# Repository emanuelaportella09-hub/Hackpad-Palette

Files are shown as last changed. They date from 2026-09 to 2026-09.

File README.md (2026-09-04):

# Hackpad-Palette
A Hackpad where you can switch colors on Paint for Windows 11.

I tried to make a keyboard for when I use Paint, to change colors like a real palette.

IT ONLY WORKS FOR PAINT ON WINDOWS 11.
IT WON'T WORK FOR OTHER SOFTWARE.

It was fun to make, and it taught me more about the production process of keyboards. It's really interesting, because out there is a whole community that loves this kind of hardware.

# FEATURES
- 128x32 OLED display
- 16 keys
- Can change colors on Paint on Windows 11

# PCB
I used EasyEDA for this project since I know how to use it a little, unlike KiCad.




# SCHEMATICS
SCH_Schematic1_1-P1_2026-09-04

# CAD
Plate only



Case and plate



Case, plate, and PCB all together. I couldn't put the 3D file of the PCB in Onshape because it was buggy for some reason, so I decided to put a rectangle inside with the same measurements as the board instead.



# BOM

16x MX Switches

1x XIAO RP2040

16x Differently Colored DSA Keycaps

4x M3x16 Bolt

4x M3 Heatset

1x 0.91" 128x32 OLED Display

16x Through-hole 1N4148 Diodes

1x Case.step in PRODUCTION FOLDER needs to be 3d printed

1x Plate.step in PRODUCTION FOLDER needs to be 3d printed

#**EXTRA NEDDED:**

Soldering Iron

My firmware

Arduino IDE installed on a computer

AutoHotKey installed on a computer

#**TESTING:**

Few Jump Wires

Breadboard

Usb-c to usb cable

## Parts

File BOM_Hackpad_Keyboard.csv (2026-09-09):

Item | Component / Part | Quantity | Category | Notes
1 | MX Switches | 16 | Hardware / Component | Key switches
2 | XIAO RP2040 | 1 | Microcontroller | Main MCU board
3 | DSA Keycaps (Differently Colored) | 16 | Hardware | Keycaps
4 | M3x16 Bolt | 4 | Fastener | Hardware mounting
5 | M3 Heatset Insert | 4 | Fastener | 3D print insert
6 | 0.91" 128x32 OLED Display | 1 | Display | I2C OLED screen
7 | 1N4148 Diodes (Through-hole) | 16 | Electronic Component | Switch matrix diodes
8 | Case.step | 1 | 3D Print | Located in PRODUCTION FOLDER (Needs 3D printing)
9 | Plate.step | 1 | 3D Print | Located in PRODUCTION FOLDER (Needs 3D printing)
10 | Soldering Iron | 1 | Extra Needed / Tool | Assembly tool
11 | Firmware | 1 | Software / Code | Custom keyboard firmware
12 | Arduino IDE | 1 | Software | Installed on computer
13 | AutoHotKey | 1 | Software | Installed on computer
14 | Jump Wires | 1 | Testing Equipment | Few wires for breadboarding
15 | Breadboard | 1 | Testing Equipment | For testing before soldering
16 | USB-C to USB Cable | 1 | Testing Equipment / Cable | Power and data connection

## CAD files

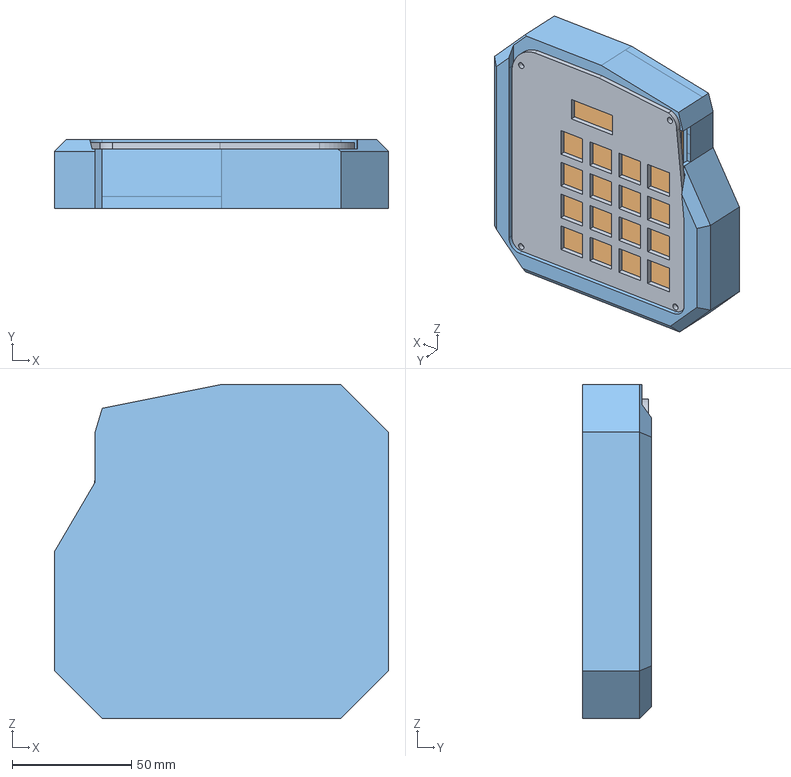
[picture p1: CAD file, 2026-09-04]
CAD/hackpad.step
140.0 x 29.0 x 140.0 mm
plate
pcb
case

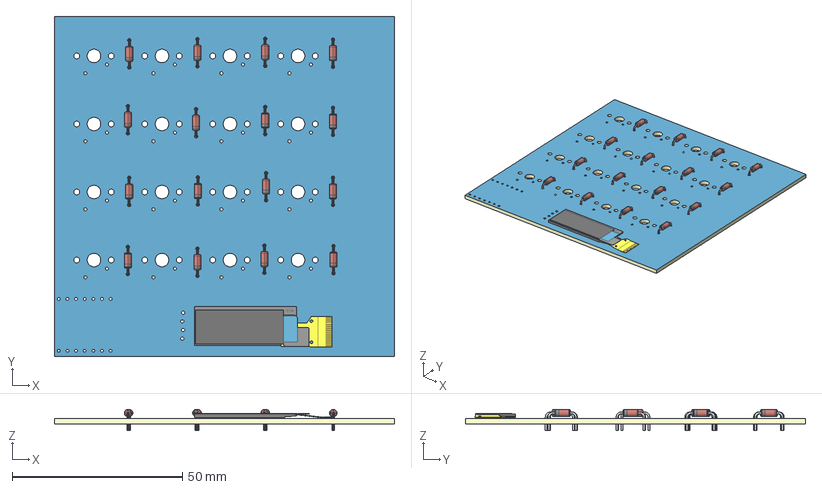
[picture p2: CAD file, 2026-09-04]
PCB/3D_PCB1_2026-09-04.step
100.0 x 100.0 x 6.21 mm
Board~ctDM
TopCopper~ctDM
BottomCopper~ctDM
TopSilkscreen~ctDM
BottomSilkscreen~ctDM
TopFpcStiffener~ctDM
BottomFpcStiffener~ctDM
DO-35_BD2.0-L4.0-P8.00-D0.5-FD~DO-35_BD2.0-L4.0-P8.00-D0.5-FD~vYH5 x 16
OLED-TH-C128-R64-D0.91-I2C-SSD1306-STAG5~OLED_L40.5-W11.5-H1.2-QG-2832TLBFG02~vior

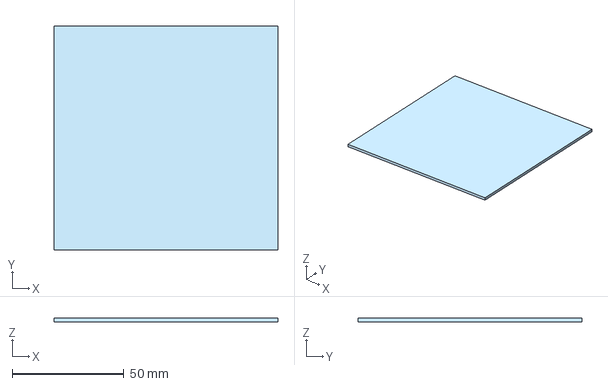
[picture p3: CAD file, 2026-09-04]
CAD/pcb.step
100.0 x 100.0 x 1.60 mm

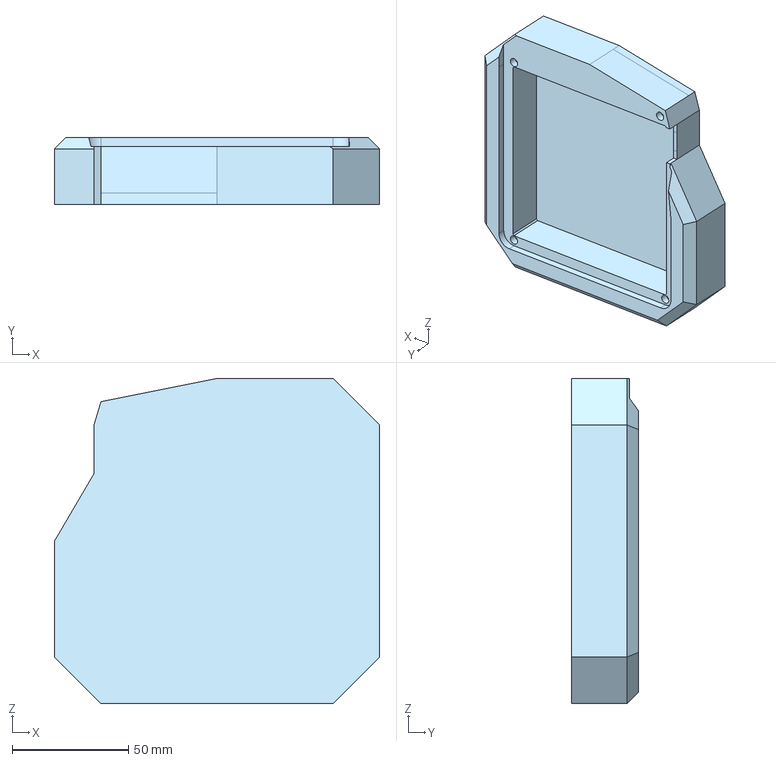
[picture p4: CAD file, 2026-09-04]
Production/case.step
140.0 x 29.0 x 140.0 mm

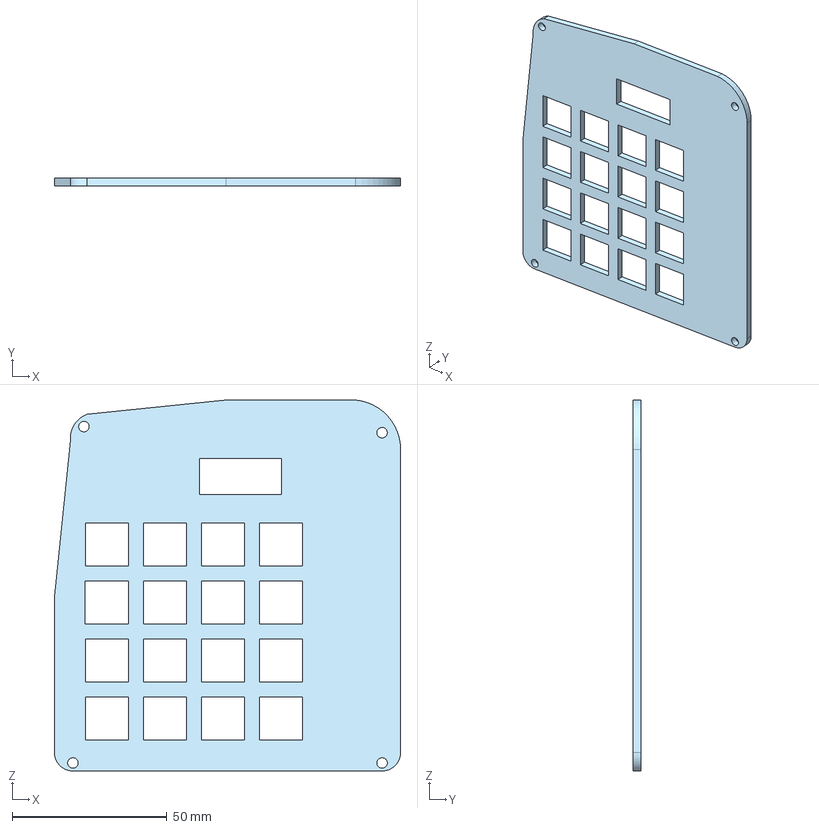
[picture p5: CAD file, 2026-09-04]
Production/plate.step
112.0 x 2.70 x 120.0 mm

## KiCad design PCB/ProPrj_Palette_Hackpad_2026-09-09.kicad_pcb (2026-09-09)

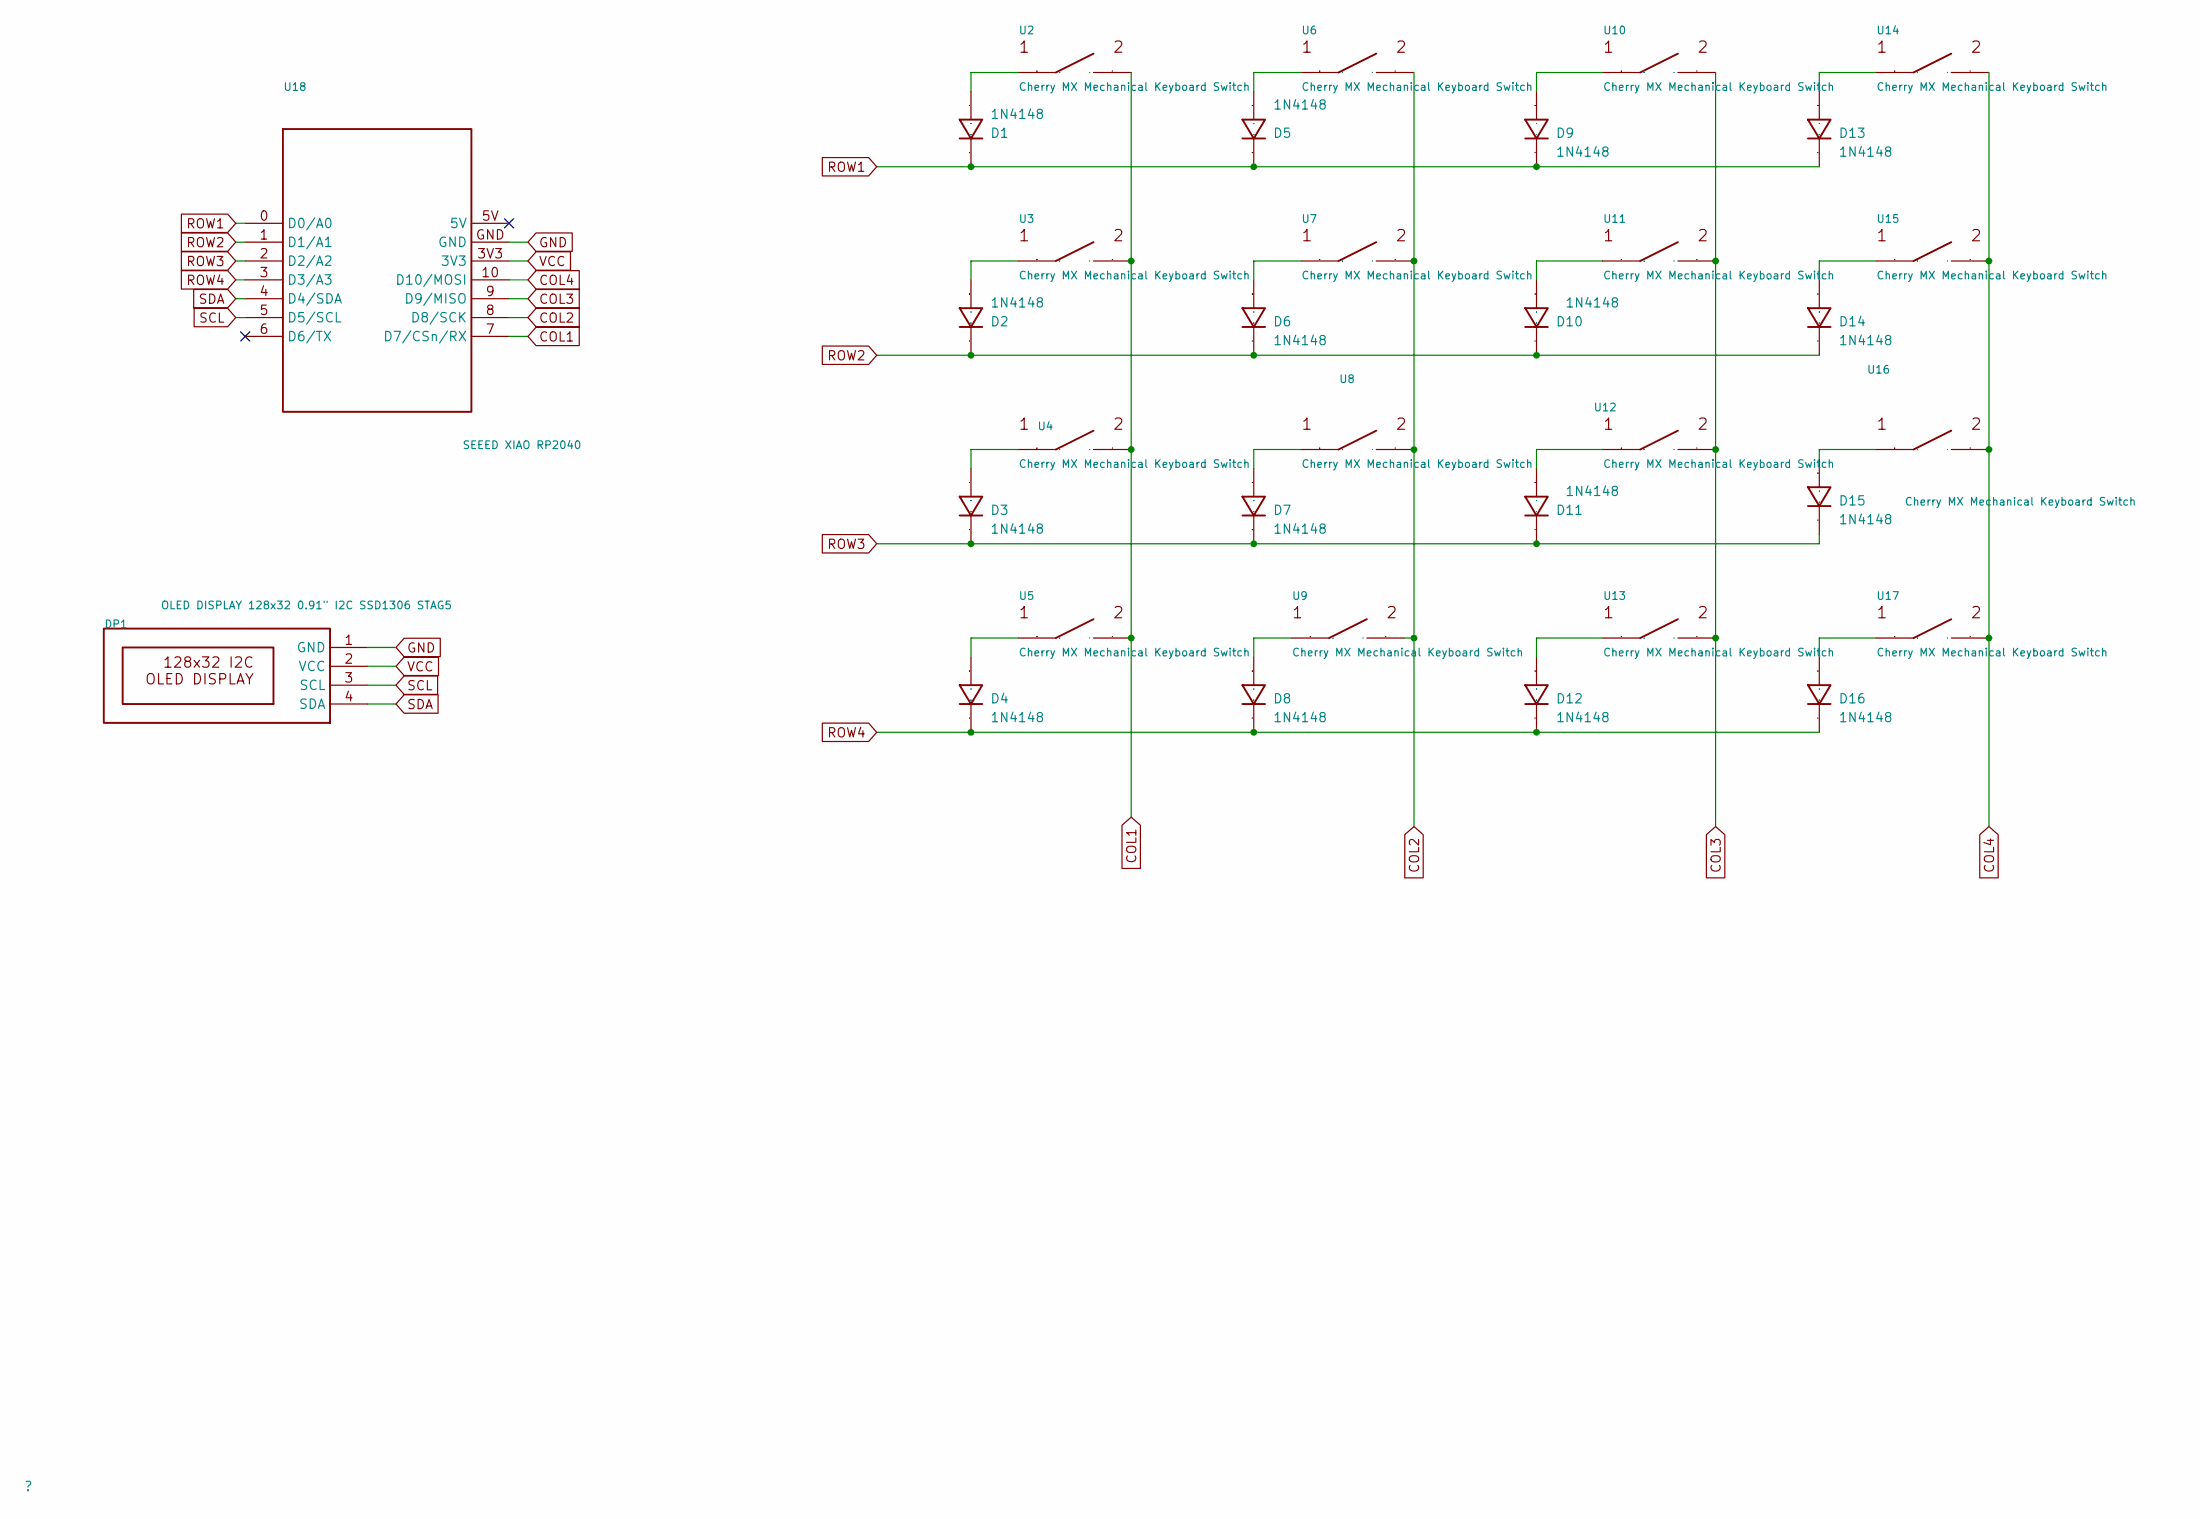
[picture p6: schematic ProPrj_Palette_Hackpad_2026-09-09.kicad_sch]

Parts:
D1, D2, D3, D4, D5, D6, D7, D8, D9, D10, D11, D12, D13, D14, D15, D16: 1N4148; DO-35_BD2.0-L4.0-P8.00-D0.5-FD; Manufacturer Part 1N4148; LCSC Part Name 100V 200mA
DP1: OLED DISPLAY 128x32 0.91" I2C SSD1306 STAG5; OLED-TH-C128-R64-D0.91-I2C-SSD1306-STAG5
U2, U3, U4, U5, U6, U7, U8, U9, U10, U11, U12, U13, U14, U15, U16, U17: Cherry MX Mechanical Keyboard Switch; CHERRY MX KEYSWITCH
U18: SEEED XIAO RP2040; XIAO RP2040 V1.22_BOARD

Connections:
$1N3: D1.1 (A), U2.1
$1N4: D2.1 (A), U3.1
$1N5: D3.1 (A), U4.1
$1N7: D4.1 (A), U5.1
$1N8: D5.1 (A), U6.1
$1N9: D6.1 (A), U7.1
$1N10: D7.1 (A), U8.1
$1N11: D8.1 (A), U9.1
$1N12: D9.1 (A), U10.1
$1N13: D10.1 (A), U11.1
$1N14: D11.1 (A), U12.1
$1N15: D12.1 (A), U13.1
$1N17: D13.1 (A), U14.1
$1N18: D14.1 (A), U15.1
$1N21: D15.1 (A), U16.1
$1N22: D16.1 (A), U17.1
COL1: U2.2, U3.2, U4.2, U5.2, U18.7 (D7/CSn/RX)
COL2: U6.2, U7.2, U8.2, U9.2, U18.8 (D8/SCK)
COL3: U10.2, U11.2, U12.2, U13.2, U18.9 (D9/MISO)
COL4: U14.2, U15.2, U16.2, U17.2, U18.10 (D10/MOSI)
GND: DP1.1 (GND), U18.GND
ROW1: D1.2 (K), D5.2 (K), D9.2 (K), D13.2 (K), U18.0 (D0/A0)
ROW2: D2.2 (K), D6.2 (K), D10.2 (K), D14.2 (K), U18.1 (D1/A1)
ROW3: D3.2 (K), D7.2 (K), D11.2 (K), D15.2 (K), U18.2 (D2/A2)
ROW4: D4.2 (K), D8.2 (K), D12.2 (K), D16.2 (K), U18.3 (D3/A3)
SCL: DP1.3 (SCL), U18.5 (D5/SCL)
SDA: DP1.4 (SDA), U18.4 (D4/SDA)
VCC: DP1.2 (VCC), U18.3V3

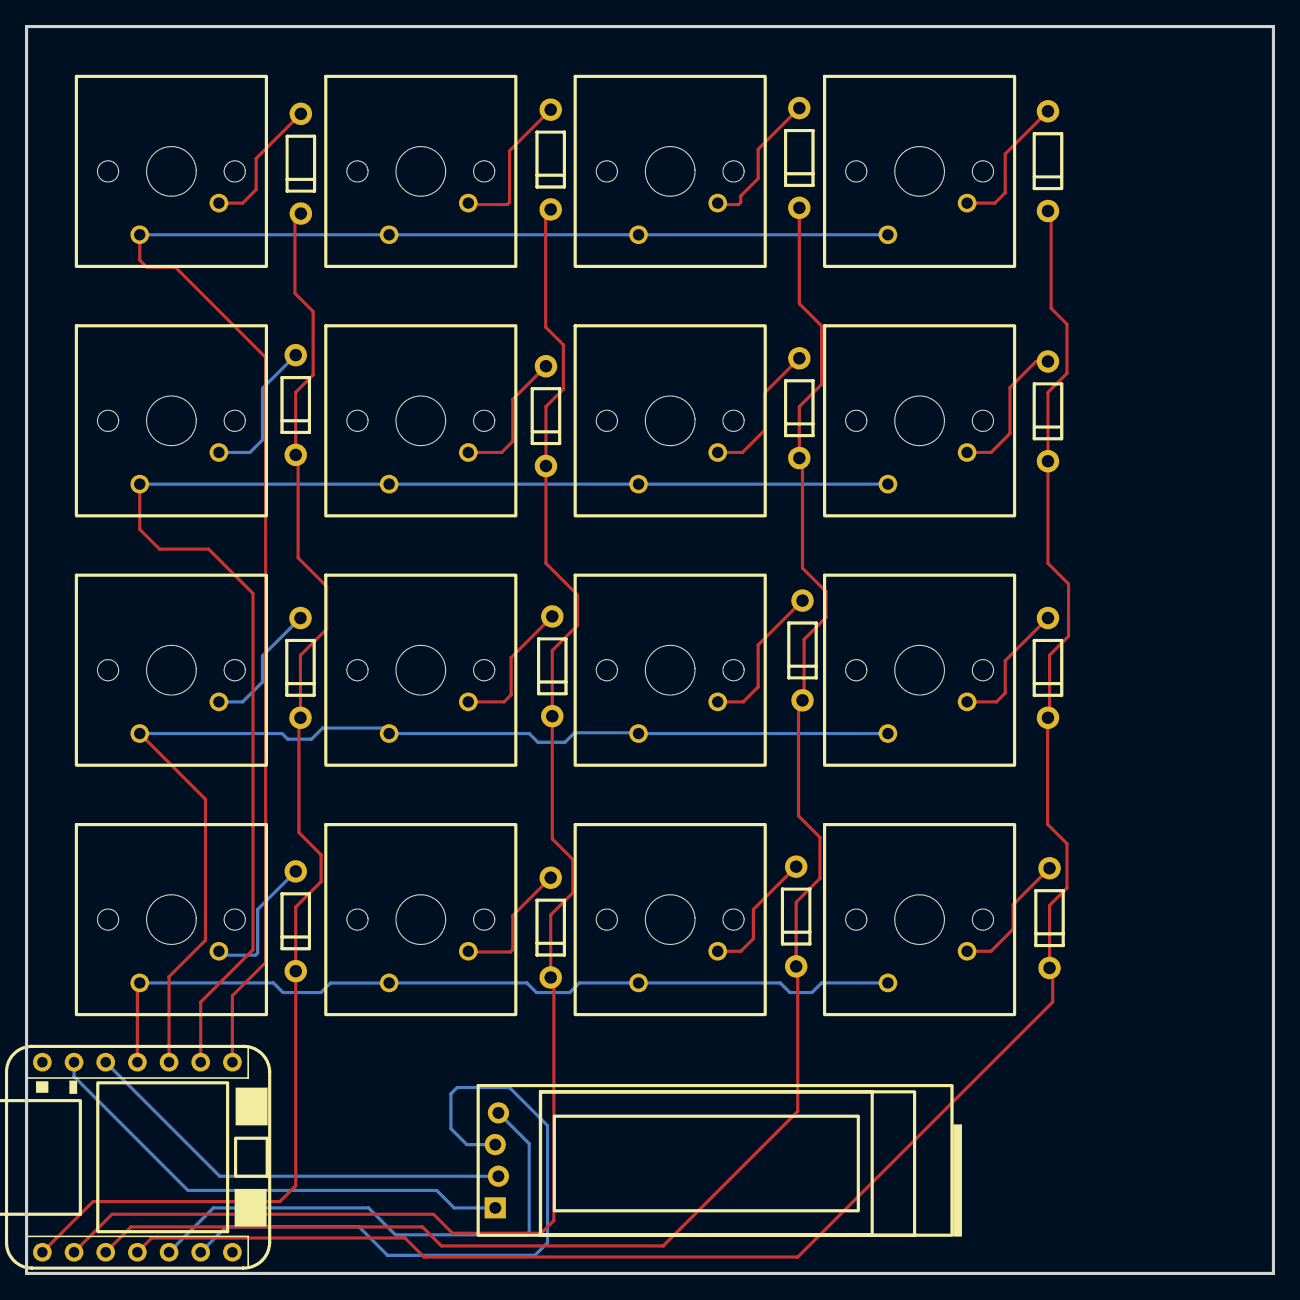
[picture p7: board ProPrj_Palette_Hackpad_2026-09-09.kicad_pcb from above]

Board: 2 copper layers, 100.0 x 100.0 mm, 34 parts (0 on the bottom side), 28 nets.

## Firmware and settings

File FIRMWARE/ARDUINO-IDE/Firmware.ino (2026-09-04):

#include <Keyboard.h>
#include <Wire.h>
#include <Adafruit_GFX.h>
#include <Adafruit_SSD1306.h>


#define SCREEN_WIDTH 128
#define SCREEN_HEIGHT 32
#define OLED_RESET -1
Adafruit_SSD1306 display(SCREEN_WIDTH, SCREEN_HEIGHT, &Wire, OLED_RESET);

#define NUM_ROWS 4
#define NUM_COLS 4

int pinRow[NUM_ROWS] = {0,1,2,3};
int pinColomn[NUM_COLS] = {7,8,9,10};

int mapButtons[NUM_ROWS][NUM_COLS] = {
  {KEY_F13, KEY_F14 , KEY_F15 , KEY_F16 },
  {KEY_F17, KEY_F18 , KEY_F19 , KEY_F20 },
  {KEY_F21, KEY_F22 , KEY_F23 , KEY_F24 },
  {KEY_KP_1, KEY_KP_2 , KEY_KP_3 , KEY_KP_4}
};


String mapNames [NUM_ROWS][NUM_COLS] ={
  {"Rosso","Arancione", "Giallo","Verde"},
  {"Ciano","Blu","Viola","Magenta"},
  {"Rosa","Marrone","Nero","Bianco"},
  {"Grigio", "Verde scuro", "Blu scuro", "Oro"},
};

bool statebefore[NUM_ROWS][NUM_COLS];

void setup() {
  Keyboard.begin();



  display.begin(SSD1306_SWITCHCAPVCC,0x3C);
  display.clearDisplay();
  display.setTextSize(2);
  display.setTextColor(SSD1306_WHITE);
  display.setCursor(0,8);
  display.println("Palette");
  display.display();



  for(int r =0; r < NUM_ROWS; r++ ){
    pinMode(pinRow[r], OUTPUT);
    digitalWrite(pinRow[r], HIGH);
  }

  for(int c =0; c < NUM_COLS; c++ ){
    pinMode(pinColomn[c], INPUT_PULLUP);
  }

   for(int r =0; r < NUM_ROWS; r++ ){
    for(int c =0; c < NUM_COLS; c++ ){
      statebefore[r][c] = HIGH;
    }}
}

void loop() {
  scanMatrix();
  delay(5);
}

void scanMatrix(){
  for(int r =0; r < NUM_ROWS; r++ ){
    digitalWrite(pinRow[r],LOW);
    for(int c =0; c < NUM_COLS; c++ ){
      bool stateNow = digitalRead(pinColomn[c]);
      if (stateNow == LOW && statebefore[r][c] == HIGH){
        Keyboard.press(mapButtons[r][c]);
        Keyboard.release(mapButtons[r][c]);
        showColorOnDisplay(mapNames[r][c]);
      }
      statebefore[r][c] = stateNow;
    }
    digitalWrite(pinRow[r],HIGH);
  }
}

void showColorOnDisplay(String ColorName){
  display.clearDisplay();
  display.setTextSize(2);
  display.setTextColor(SSD1306_WHITE);
  display.setCursor(0,8);
  display.println(ColorName);
  display.display();

}

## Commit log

2026-09-04 Create BOM
2026-09-04 Rename case (1).step to case.step
    [case.step]
2026-09-04 Rename hackpad (1).step to hackpad.step
    [hackpad.step]
2026-09-04 Update BOM
